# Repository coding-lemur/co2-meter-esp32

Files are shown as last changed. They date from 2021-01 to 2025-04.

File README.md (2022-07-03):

# CO2 Meter with ESP32

## Description

Messasure CO2 particles in to the air.
Warns when you should ventilate the room.

You find an video documentary (in german) on my Youtube channel:
https://www.youtube.com/watch?v=MKK0GAGxzaE

## Features

- Measure CO2 concentration in room
- MQTT support (for Node-Red or Home Assistant)
- easy integration in own WiFi network (Hotspot settings-page)
- OLED display: can used independently thanks to the measured values shown on the display

## Parts

- [ESP32 Development Board \*](https://www.banggood.com/custlink/mKDYaR8Uuc)
- [NDIR CO2 Sensor MH-Z14A \*](https://www.banggood.com/custlink/DmDhaY8k79)
- [0.96 Inch OLED Display 128\*64 SSD1306 \*](https://www.banggood.com/custlink/3DmyLhZMwa)

`* Affiliate Links - help to support my projects`

## Sketch

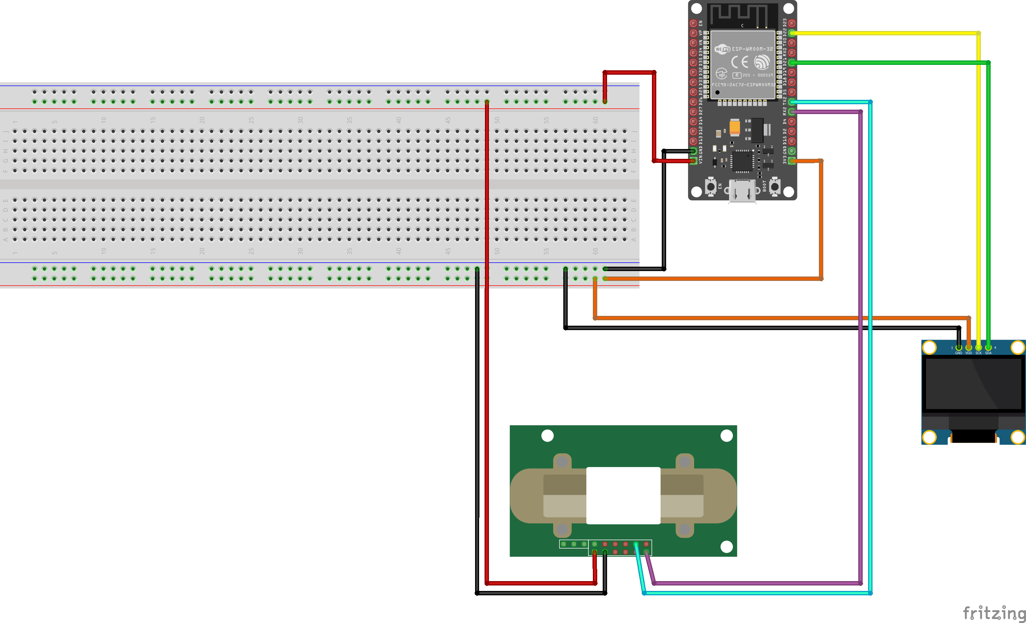
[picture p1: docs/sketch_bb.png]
sketch


## Wiring

### CO2 sensor (MH-Z14A)

| Pin on Sensor | description | Pin on ESP32 |
| --- | --- | --- |
| 16 | GND | GND |
| 17 | Power (5V)  | VIN (can also used as 5V output) |
| 18 | UART RXD | GPIO17 (UART 2 TX) |
| 19 | UART TXD | GPIO16 (UART 2 RX) |

### OLED display (SSD1306)

| Pin on Sensor | description  | Pin on ESP32 |
| --- | --- | --- |
| GND | GND | GND |
| VCC | Power (3.3V) | 3V3 |
| SCL | | GPIO22 (I2C SCL) |
| SDA | | GPIO21 (I2C SDA) |

## Setup

- connect all parts to the ESP32
- connect power
- the ESP32 starting an own Wifi access point named "co2-meter-{device ID}"
- connect to this Wifi with your smartphone
- use `waaatering` for Wifi password
- you will redirected to a config page
- insert your Wifi and MQTT broker credentials
- click on "save"
- the ESP32 will restarting and connect to your MQTT broker
- after about 60 seconds should you should see a new topic in your MQTT broker `co2-meter/{device ID}/out/info` with a lot of information in the payload

## MQTT API

The whole module is controllable via MQTT protocol. So it's easy to integrate in existing SmartHome systems (like Home Assistant or Node-Red).

### Incoming commands

Topic: co2-meter/`{device ID}`/in/`{command}`

| command | description | payload |
| --- | --- | --- |
| sleep | Start deep-sleep for specific duration (in seconds!) | { duration: number } |
| info | Send info via MQTT topic `co2-meter/out/info` package | - |
| display | turn display on/off | { on: boolean } |
| hard-reset | Reset config with WiFi and MQTT settings and start internal hotspot to reconfigure device. | - |

### Outcoming commands

Topic: co2-meter/`{device ID}`/out/`{command}`

| command | description | payload |
| --- | --- | --- |
| info | status info | complex JSON. See "info-state" chapter |
| sleep | was send if sytem enter deep-sleep | { duration: number } |
| wakeup  | was send if sytem wakeup from deep-sleep | reason "timer" |

#### Info state

| field | description | type |
| --- | --- | --- |
| version | version number of module firmware | string  |
| system.deviceId | Unique ID of the device. Will used also in MQTT topics. | string  |
| system.freeHeap | free heap memory of CPU | number  |
| network.wifiRssi | wifi signal strength (RSSI) | number  |
| network.wifiQuality | quality of signal strength (value between 0 and 100%) | number  |
| network.wifiSsid | SSID of connected wifi | string  |
| network.ip | ip address of the module | string  |
| network.mac | MAC address of the device | string  |
| co2.isPreheating | TRUE if the sensor is preheated | boolean |
| co2.temperature | temperature from sensor (in °C) | number  |
| co2.ppm | CO2 concentration in the air (in ppm) | number  |

## Housing

You can create a robust housing with a 3D printer or at the workbench.

I decided to make one out of plywood. It didn't turn out perfect, but it protects the components.

sketch

## TODOs

- [x] buy sensor and ESP32
- [x] soldering first prototype
- [x] add WifiManager to easy setup
- [x] create sketch
- [x] test firmware
- [x] test OTA updates
- [x] add part list
- [x] add video doc
- [x] create housing (from wood)

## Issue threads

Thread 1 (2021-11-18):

Can't compile without warnings

joopy, 2021-11-18:
Using Atom with platform IO.
What SoftwareSerial library needs to be installed?

Keep getting compile errors.

MCeddy, 2021-11-20:
Hey Joppy. Thanks for contacting me. I also noticed your Youtube comment on my channel :)

I fixed the problem with the missing SoftwareSerial dependency. Hope that helps.

Best regards

René

joopy, 2021-11-22:
Hey René,

Thanks for the help! compiling is working so that's great. Config true webinterface and connecting to mqtt (home assistant) is working. But the json payload is not compleet:

{"version":"1.0.0","system":{"deviceId":"ccf95b","freeHeap":235316},"network":{"wifiRssi":-50,"wifiQuality":100,"wifiSsid":"secretssid","ip":"192.168.1.18"},"co2":{"isPreheating":false,"isReady":false}}

Can you enlight me?

Best regards
jeroen

joopy, 2021-11-22:
isReady is not true. But display is working and showing co2 ppm

MCeddy, 2022-01-07:
Hey Joopy. Happy new year :)

I'm in trouble at end of the year like everyone. But today I found time to fix the error: I removed the caches for sensor values and read the values live on generating the JSON result. So it should be correct.

Hope that helps. Happy coding & best regards :)

René

MCeddy, 2022-01-07:
I tested the original isReady value from the MZ library. But dosn't understand when it's TRUE. It's always FALSE. But the sensor value and isPreheating works :)

MCeddy, 2022-01-08:
in v1.1.3 I removed the isReady field from JSON. So it's only important to check isPreheating field (while TRUE the sensor value is still 0) :)

joopy, 2022-02-16:
> in v1.1.3 I removed the isReady field from JSON. So it's only important to check isPreheating field (while TRUE the sensor value is still 0) :)

Yes it's working correctly now.

Closed 2022-01-07.

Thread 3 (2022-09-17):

ESP32 reboots permanently

DirkausHH, 2022-09-17:
Hi,

very nice project. After some hassle I'm now able to compile it with PlatfomIO, but the device goes in a reboot loop afterwards.
I adapted the ini to my Lolino32 and currently neither the sensor nor the display is connected, but I can't even reach the AP mode.

The monitor provides the following output:

Rebooting...
ets Jun  8 2016 00:22:57

rst:0xc (SW_CPU_RESET),boot:0x13 (SPI_FAST_FLASH_BOOT)
configsip: 0, SPIWP:0xee
clk_drv:0x00,q_drv:0x00,d_drv:0x00,cs0_drv:0x00,hd_drv:0x00,wp_drv:0x00
mode:DIO, clock div:2
load:0x3fff0018,len:4
load:0x3fff001c,len:1044
load:0x40078000,len:10124
load:0x40080400,len:5828
entry 0x400806a8
assertion "Invalid mbox" failed: file "/home/runner/work/esp32-arduino-lib-builder/esp32-arduino-lib-builder/esp-idf/components/lwip/lwip/src/api/tcpip.c", line 416, function: tcpip_api_call
abort() was called at PC 0x40101de3 on core 1

ELF file SHA256: 0000000000000000

Backtrace: 0x40089520:0x3ffb1df0 0x4008979d:0x3ffb1e10 0x40101de3:0x3ffb1e30 0x4012927f:0x3ffb1e60 0x400dd637:0x3ffb1e90 0x400e24be:0x3ffb1ee0 0x400d1ba9:0x3ffb1f00 0x400d232c:0x3ffb1f40 0x400e74e2:0x3ffb1fb0 0x4008a7ae:0x3ffb1fd0
  #0  0x40089520:0x3ffb1df0 in invoke_abort at /home/runner/work/esp32-arduino-lib-builder/esp32-arduino-lib-builder/esp-idf/components/esp32/panic.c:715
  #1  0x4008979d:0x3ffb1e10 in abort at /home/runner/work/esp32-arduino-lib-builder/esp32-arduino-lib-builder/esp-idf/components/esp32/panic.c:715
  #2  0x40101de3:0x3ffb1e30 in __assert_func at /Users/ivan/e/newlib_xtensa-2.2.0-bin/newlib_xtensa-2.2.0/xtensa-esp32-elf/newlib/libc/stdlib/../../../.././newlib/libc/stdlib/assert.c:63 (discriminator 8)
  #3  0x4012927f:0x3ffb1e60 in tcpip_api_call at /home/runner/work/esp32-arduino-lib-builder/esp32-arduino-lib-builder/esp-idf/components/lwip/lwip/src/api/tcpip.c:483
  #4  0x400dd637:0x3ffb1e90 in AsyncServer::begin() at .pio\libdeps\esp32dev\AsyncTCP-esphome\src/AsyncTCP.cpp:1074
      (inlined by) AsyncServer::begin() at .pio\libdeps\esp32dev\AsyncTCP-esphome\src/AsyncTCP.cpp:1330
  #5  0x400e24be:0x3ffb1ee0 in AsyncWebServer::begin() at .pio\libdeps\esp32dev\ESPAsyncWebServer-esphome\src/WebServer.cpp:181
  #6  0x400d1ba9:0x3ffb1f00 in setupWebserver() at .pio/libdeps/esp32dev/ArduinoJson/src/ArduinoJson/Misc/SafeBoolIdiom.hpp:15
  #7  0x400d232c:0x3ffb1f40 in setup() at .pio/libdeps/esp32dev/ArduinoJson/src/ArduinoJson/Misc/SafeBoolIdiom.hpp:15
  #8  0x400e74e2:0x3ffb1fb0 in loopTask(void*) at C:\Users\Dirk\.platformio\packages\framework-arduinoespressif32\cores\esp32/main.cpp:18
  #9  0x4008a7ae:0x3ffb1fd0 in vPortTaskWrapper at /home/runner/work/esp32-arduino-lib-builder/esp32-arduino-lib-builder/esp-idf/components/freertos/port.c:355 (discriminator 1)

DirkausHH, 2022-09-19:
I got the 1.1.3 to work.
The platformio.ini lib_deps must be updated to tobiasschuerg/MH-Z CO2 Sensors @ ~**1.4.0**
Otherwise the build fails.
The current 1.2.0 version still won't boot...

coding-lemur, 2022-09-19:
Hi Dirk. I'm glad you like my project. :)
I checked the dependencies: In my latest version (1.1.3) I'm already unsing the 1.4.0 version of the CO2 sensor lib. So it should compile. But I'm used the evening to update a few libraries to the current version.

best regards

René

Closed 2022-09-21.

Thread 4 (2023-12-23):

unexpected readings and weird temperature and co2 values

bbregman, 2023-12-23:
hello @coding-lemur , i have followed your instructions to connect all the hardware bits, downloaded the software from github, compiled it into platformio in visualstudio code (needed to change some version numbers for the dependency libs otherwise the project would not compile, gave some errors and warnings) and uploaded the software to the esp32-devkit board. led display is working, co2sensor is blinking red twice a second I think and says:
- temperature: 0
- co2: -2
- unexpected readings .....

Do you know what is missing for a good reading?
- is the co2 sensor not working well, or not correctly connected?
- is the software incorrectly reading or calculating the values?

thanks in advance!

bbregman, 2024-01-16:
hello @coding-lemur , thank you for your reply. eventually i figured it out by using esphome and resetting the co2 sensor, then the values came in and the software was working. thanks again for your clear documentation, this helped me a lot in building the device and troubleshooting the issue.

bbregman, 2024-01-16:
i guess this issue can be marked as closed :)

Closed 2024-01-16.

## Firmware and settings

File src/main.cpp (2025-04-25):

#include <Wire.h>
#include <WiFi.h>
#include <WiFiManager.h>
#include <ArduinoOTA.h>
#include <LittleFS.h>
#include <ArduinoJson.h>
#include <StreamUtils.h>
#include <MHZ.h>
#include <AsyncMqttClient.h>
#include <Adafruit_GFX.h>
#include <Adafruit_SSD1306.h>
#include <Adafruit_I2CDevice.h>
#include <ESPAsyncWebServer.h>
#include <SoftwareSerial.h>
#include <tools.h>

#include "config.h"

Adafruit_SSD1306 display(SCREEN_WIDTH, SCREEN_HEIGHT, &Wire);
MHZ co2Sensor(&Serial2, MHZ::MHZ14A);
WiFiManager wifiManager;
WiFiClient espClient;
AsyncMqttClient mqttClient;
static AsyncWebServer server(80);

TimerHandle_t mqttReconnectTimer;
TimerHandle_t wifiReconnectTimer;

// timers
unsigned long lastCo2Measurement = 0;

// custom parameters

char mqtt_server[40] = "mqtt.example.com";
char mqtt_port[6] = "1883";
char mqtt_user[20];
char mqtt_password[20];

WiFiManagerParameter custom_mqtt_server("server", "mqtt server", mqtt_server, 40);
WiFiManagerParameter custom_mqtt_port("port", "mqtt port", mqtt_port, 6);
WiFiManagerParameter custom_mqtt_user("user", "mqtt user", mqtt_user, 40);
WiFiManagerParameter custom_mqtt_password("password", "mqtt password", mqtt_password, 40);

const String chipId = getChipId();
const String objectId = "co2meter_" + chipId;

const String mqttStateTopic = "co2meter/" + chipId + "/state";
const String mqttDiscoverTopic = "homeassistant/sensor/co2meter/config";

byte appState = 0; // 0 = init; 1 = preheating; 2 = ready

int lastTemperature = 0;
int lastCo2Value = 0;

bool shouldSaveConfig = false; // flag for saving data
bool configLoaded = false;     // flag for config loaded

bool isWifiConnected = false;
bool isMqttConnected = false;

byte failedMqttConntections = 0;

void publishHomeAssistantDiscovery()
{
    JsonDocument doc;
    doc["name"] = "CO2 Meter";
    doc["uniq_id"] = objectId;
    doc["unit_of_meas"] = "ppm";
    doc["dev_cla"] = "carbon_dioxide";
    doc["stat_t"] = mqttStateTopic;
    doc["val_tpl"] = "{{ value_json.co2|default(0) }}";

    JsonObject dev = doc["dev"].to<JsonObject>();
    dev["ids"] = chipId;
    dev["name"] = objectId;
    dev["sw"] = VERSION;
    dev["mf"] = "coding-lemur";
    dev["mdl"] = "CO2 Meter";
    dev["cu"] = WiFi.localIP().toString();

    // serialize JSON and send discover-topic
    StringStream stream;
    size_t n = serializeJson(doc, stream);
    mqttClient.publish(mqttDiscoverTopic.c_str(), 0, true, stream.str().c_str(), n);
}

void publishSensorState(int co2Value)
{
    JsonDocument doc;
    doc["co2"] = co2Value;

    // serialize JSON and send topic
    StringStream stream;
    size_t n = serializeJson(doc, stream);
    mqttClient.publish(mqttStateTopic.c_str(), 0, false, stream.str().c_str(), n);
}

void connectToMqtt()
{
    if (mqttClient.connected())
    {
        Serial.println("Already connected to MQTT");
        return;
    }

    failedMqttConntections++;

    if ((failedMqttConntections > 3) && (mqttReconnectTimer != nullptr))
    {
        Serial.println("too many failed MQTT connections..");

        xTimerDelete(mqttReconnectTimer, 0);
        mqttReconnectTimer = nullptr;

        Serial.println("mqttReconnectTimer deleted.");
        return;
    }

    if (strlen(mqtt_server) == 0)
    {
        Serial.println("MQTT server not configured. Skipping MQTT connection.");
        return;
    }

    uint16_t mqttPortValue = static_cast<uint16_t>(strtol(mqtt_port, nullptr, 10));
    mqttClient.setServer(mqtt_server, mqttPortValue);

    if (strlen(mqtt_user) > 0)
        mqttClient.setCredentials(mqtt_user, mqtt_password);

    Serial.println("Connecting to MQTT...");

    /*Serial.println("MQTT Server: " + String(mqtt_server));
    Serial.println("MQTT Port: " + String(mqtt_port));
    Serial.println("MQTT User: " + String(mqtt_user));
    Serial.println("MQTT Password: " + String(mqtt_password));*/

    mqttClient.connect();
}

void WiFiEvent(WiFiEvent_t event)
{
    Serial.printf("[WiFi-event] event: %d\n", event);
    switch (event)
    {
    case SYSTEM_EVENT_STA_GOT_IP:
        Serial.println("WiFi connected");
        Serial.println("IP address: ");
        Serial.println(WiFi.localIP());

        isWifiConnected = true;
        connectToMqtt();
        break;
    case SYSTEM_EVENT_STA_DISCONNECTED:
        Serial.println("WiFi lost connection");
        xTimerStop(mqttReconnectTimer, 0); // ensure we don't reconnect to MQTT while reconnecting to Wi-Fi
        xTimerStart(wifiReconnectTimer, 0);
        break;
    }
}

const char *createHostname(String prefix)
{
    String hostname = prefix + '-' + chipId;
    return hostname.c_str();
}

void setupWifi()
{
    WiFi.setHostname(createHostname(String(HOST_NAME)));

    WiFi.mode(WIFI_STA);
    WiFi.onEvent(WiFiEvent);
    WiFi.begin();
}

void saveConfig()
{
    // save config
    Serial.println("Saving config...");

    File configFile = LittleFS.open(CONFIG_FILE_PATH, "w");
    if (!configFile)
    {
        Serial.println("Failed to open config file for writing");
        return;
    }

    JsonDocument jsonDoc;
    jsonDoc["mqtt_server"] = mqtt_server;
    jsonDoc["mqtt_port"] = mqtt_port;
    jsonDoc["mqtt_user"] = mqtt_user;
    jsonDoc["mqtt_password"] = mqtt_password;

    serializeJson(jsonDoc, configFile);
    configFile.close();

    shouldSaveConfig = false;
}

void connectToWifi()
{
    if (WiFi.isConnected())
    {
        Serial.println("Already connected to WiFi");
        return;
    }

    String hostname = String(HOST_NAME) + "-AP";
    auto isConnected = wifiManager.autoConnect(hostname.c_str(), AP_PASSWORD);

    if (isConnected)
    {
        Serial.println("connected to wifi");

        if (!configLoaded)
        {
            // read updated parameters
            strcpy(mqtt_server, custom_mqtt_server.getValue());
            strcpy(mqtt_port, custom_mqtt_port.getValue());
            strcpy(mqtt_user, custom_mqtt_user.getValue());
            strcpy(mqtt_password, custom_mqtt_password.getValue());

            if (shouldSaveConfig)
                saveConfig();
        }
    }
    else
        Serial.println("config portal running");
}

void loadConfig()
{
    if (!LittleFS.exists(CONFIG_FILE_PATH))
    {
        Serial.println("No config file found, using default values");
        return;
    }

    // load settings
    File configFile = LittleFS.open(CONFIG_FILE_PATH, "r");
    if (!configFile)
    {
        Serial.println("Failed to open config file");
        return;
    }

    JsonDocument jsonDoc;
    DeserializationError error = deserializeJson(jsonDoc, configFile);
    if (error)
    {
        Serial.print("Failed to parse config file: ");
        Serial.println(error.c_str());

        configFile.close();
        return;
    }

    strlcpy(mqtt_server, jsonDoc["mqtt_server"] | "", sizeof(mqtt_server));
    strlcpy(mqtt_port, jsonDoc["mqtt_port"] | "", sizeof(mqtt_port));
    strlcpy(mqtt_user, jsonDoc["mqtt_user"] | "", sizeof(mqtt_user));
    strlcpy(mqtt_password, jsonDoc["mqtt_password"] | "", sizeof(mqtt_password));

    Serial.println("Config loaded successfully");
    configLoaded = true;
    configFile.close();
}

// callback notifying us of the need to save config
void saveConfigCallback()
{
    Serial.println("Should save config");
    shouldSaveConfig = true;
}

void setupWifiManager()
{
    wifiManager.setDebugOutput(true);

    // custom parameters
    wifiManager.addParameter(&custom_mqtt_server);
    wifiManager.addParameter(&custom_mqtt_port);
    wifiManager.addParameter(&custom_mqtt_user);
    wifiManager.addParameter(&custom_mqtt_password);

    wifiManager.setSaveConfigCallback(saveConfigCallback);
}

void setupOTA()
{
    ArduinoOTA.setHostname(createHostname(String(HOST_NAME) + "-OTA"));

    ArduinoOTA.onStart([]()
                       { Serial.println("[OTA] starting"); });
    ArduinoOTA.onEnd([]()
                     { Serial.println("\n[OTA] finished"); });
    ArduinoOTA.onError([](ota_error_t error)
                       {
        Serial.printf("[OTA] error[%u]: ", error);
        if (error == OTA_AUTH_ERROR) Serial.println("Auth error");
        else if (error == OTA_BEGIN_ERROR) Serial.println("Start error");
        else if (error == OTA_CONNECT_ERROR) Serial.println("connection error");
        else if (error == OTA_RECEIVE_ERROR) Serial.println("receive error");
        else if (error == OTA_END_ERROR) Serial.println("Ende error"); });

    ArduinoOTA.begin();
    Serial.println("[INFO] OTA ready");
}

void setupDisplay()
{
    display.begin(SSD1306_SWITCHCAPVCC, 0x3C);

    delay(1000);

    display.clearDisplay();

    // init output
    display.setTextColor(WHITE);
    display.setTextSize(1);
    display.setCursor(0, 0);
    display.print(">> co2 meter <<");

    display.display();
}

// TODO move to tools.h
JsonDocument getInfoJson()
{
    JsonDocument doc;
    doc["version"] = VERSION;

    JsonObject system = doc["system"].to<JsonObject>();
    system["deviceId"] = chipId;
    system["freeHeap"] = ESP.getFreeHeap();
    system["cpuFreq"] = ESP.getCpuFreqMHz();
    system["flashSize"] = ESP.getFlashChipSize();
    system["flashSpeed"] = ESP.getFlashChipSpeed();
    system["flashMode"] = ESP.getFlashChipMode();
    system["sdkVersion"] = ESP.getSdkVersion();
    system["chipModel"] = ESP.getChipModel();
    system["chipCores"] = ESP.getChipCores();
    system["freePsram"] = ESP.getFreePsram();

    float temp_celsius = (temperatureRead() - 32) / 1.8; // convert from Fahrenheit to Celsius
    system["temperature"] = temp_celsius;

    // network
    JsonObject network = doc["network"].to<JsonObject>();
    const int8_t rssi = WiFi.RSSI();
    network["wifiRssi"] = rssi;
    network["wifiQuality"] = getRssiAsQuality(rssi);
    network["wifiSsid"] = WiFi.SSID();
    network["ip"] = WiFi.localIP().toString();
    network["mac"] = WiFi.macAddress();

    // CO2 Meter
    JsonObject co2Meter = doc["co2"].to<JsonObject>();
    co2Meter["isPreheating"] = co2Sensor.isPreHeating();
    co2Meter["temperature"] = lastTemperature;
    co2Meter["ppm"] = lastCo2Value > 0 ? lastCo2Value : 0;

    return doc;
}

void hardReset()
{
    Serial.println("starting hard-reset");
    wifiManager.resetSettings();
    LittleFS.remove(CONFIG_FILE_PATH);

    delay(1000);
    ESP.restart();
}

void setupWebServer()
{
    server.on("/", HTTP_GET, [](AsyncWebServerRequest *request)
              { request->send(200, "text/plain", "Hi! This is a sample response."); });

    server.on("/api/info", HTTP_GET, [](AsyncWebServerRequest *request)
              {
StringStream stream;
auto size = serializeJson(getInfoJson(), stream);

request->send(stream, "application/json", size); });

    server.on("/api/hard-reset", HTTP_POST, [](AsyncWebServerRequest *request)
              {
                  request->send(200, "text/plain", "Hard reset initiated.");
                  hardReset(); });

    server.begin();
}

void onMqttConnect(bool sessionPresent)
{
    isMqttConnected = true;
    failedMqttConntections = 0;

    Serial.println("mqtt connected");

    // TODO add option to enable/disable auto-discovery
    publishHomeAssistantDiscovery();

    /*const char *subscribeTopic = getMqttTopic("in/#");

    Serial.print("mqtt subscribe: ");
    Serial.println(subscribeTopic);

    mqttClient.subscribe(subscribeTopic, 1);
    mqttClient.publish(getMqttTopic("out/connected"), 1, false);

    sendInfo();*/
}

void onMqttDisconnect(AsyncMqttClientDisconnectReason reason)
{
    Serial.println("Disconnected from MQTT.");
    isMqttConnected = false;

    if (WiFi.isConnected())
        xTimerStart(mqttReconnectTimer, 0);
}

void setupMqtt()
{
    mqttClient.onConnect(onMqttConnect);
    mqttClient.onDisconnect(onMqttDisconnect);
    // mqttClient.onSubscribe(onMqttSubscribe);
    // mqttClient.onUnsubscribe(onMqttUnsubscribe);
    // mqttClient.onMessage(onMqttMessage);
    // mqttClient.onPublish(onMqttPublish);
}

void setupTimers()
{
    mqttReconnectTimer = xTimerCreate("mqttTimer", pdMS_TO_TICKS(2000), pdFALSE, (void *)0, reinterpret_cast<TimerCallbackFunction_t>(connectToMqtt));
    wifiReconnectTimer = xTimerCreate("wifiTimer", pdMS_TO_TICKS(2000), pdFALSE, (void *)0, reinterpret_cast<TimerCallbackFunction_t>(connectToWifi));
}

void setup()
{
    Serial.begin(115200);
    Serial2.begin(9600);

    if (!LittleFS.begin(true))
        Serial.println("Failed to mount LittleFS");

    setupTimers();
    setupMqtt();
    setupWifi();
    loadConfig();
    setupWifiManager();
    connectToWifi();
    setupOTA();
    setupWebServer();

    co2Sensor.setDebug(true);
    setupDisplay();
}

void loop()
{
    ArduinoOTA.handle();

    if (co2Sensor.isPreHeating())
    {
        if (appState != 1)
        {
            appState = 1;

            display.clearDisplay();
            display.setTextSize(1);

            display.setCursor(0, 0);
            display.print("preheating...");

            display.display();
        }
    }
    else
    {
        appState = 2;

        if (lastCo2Measurement == 0 || millis() - lastCo2Measurement >= READ_SENSOR_INTERVAL)
        {
            lastTemperature = co2Sensor.getLastTemperature();
            lastCo2Value = co2Sensor.readCO2UART();

            Serial.print("temperature: ");
            Serial.println(lastTemperature);

            Serial.print("co2: ");
            Serial.println(lastCo2Value);

            publishSensorState(lastCo2Value);

            display.clearDisplay();
            display.setTextSize(2);

            display.setCursor(0, 0);

            display.setCursor(0, 10);
            display.print("CO2: ");
            display.print(lastCo2Value);

            if (lastCo2Value >= CO2_WARN_PPM)
            {
                display.setCursor(0, 40);
                display.setTextSize(2);
                display.print("VENTILATE");
            }

            display.display();

            lastCo2Measurement = millis();
        }
    }
}

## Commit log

2021-01-27 change pins to UART2; read ppm value for CO2 in loop
2021-01-28 fix setup of co2 sensor; show sensor values on display
    [main.cpp]
2021-01-29 add sketch
    [sketch.fzz]
2021-01-29 add part list, wiring; update TODOs
2021-02-14 bump version number; add command to switch on/off display
2021-02-21 add housing
2021-04-10 only send co2 sensor values if the sensor is ready; move intervals to config
2021-11-20 fix missing SoftwareSerial dependency: upgrade some dependencies
    [main.cpp]
2022-01-07 get values direct from co2-sensor on generating JSON
2022-01-07 always return temperature and co2 value
2022-01-07 fix sensor still not ready; update version number
    [main.cpp]
2022-01-08 remove isReady field from JSON because it don't work correctly
    [main.cpp]
2022-07-03 add MAC address to info output; fix naming convention
    [main.cpp]
2025-02-20 switch to upload via COM port
2025-04-13 some implementations; use new ArduinoJson version
2025-04-21 fix default values for MQTT Server and Port; fix AP hostname
    [main.cpp]
2025-04-21 remove reconnection to MQTT after 3 fails
    [main.cpp]
2025-04-24 move timers to separate method
2025-04-24 try to fix loading default MQTT settings; move config file path to config
    [main.cpp]
2025-04-24 try to fix MQTT discovery; changes for new ArduinoJson; remove some debug logs
    [main.cpp]
